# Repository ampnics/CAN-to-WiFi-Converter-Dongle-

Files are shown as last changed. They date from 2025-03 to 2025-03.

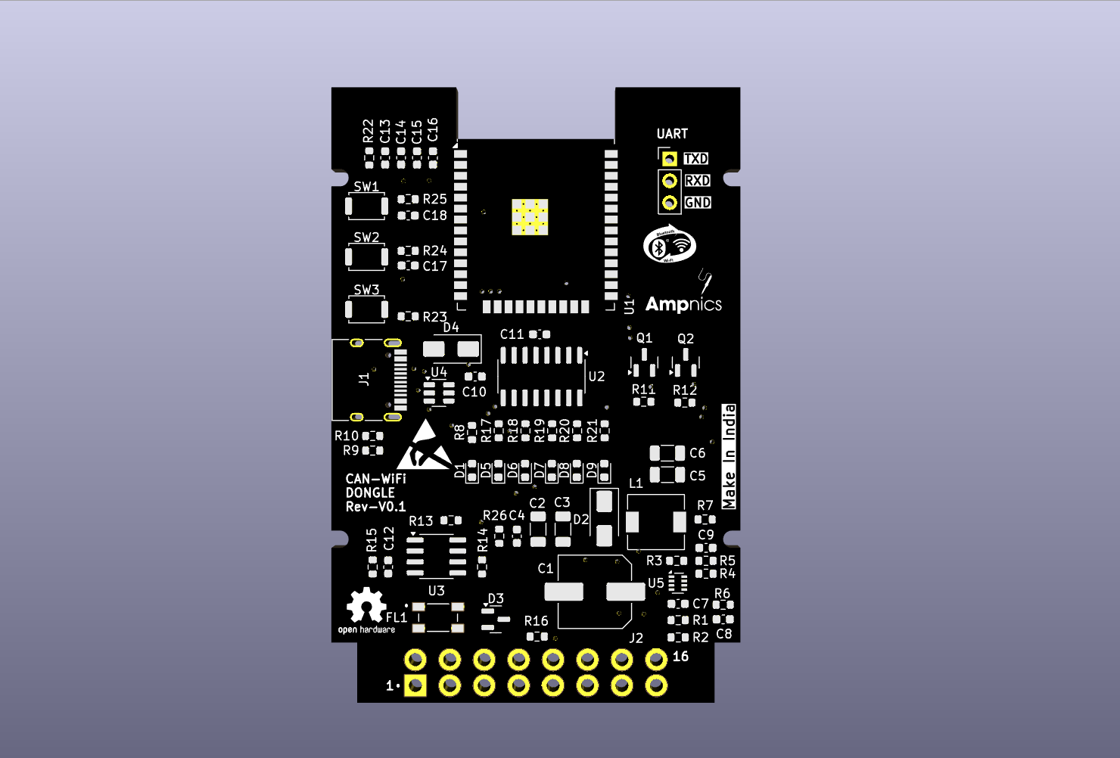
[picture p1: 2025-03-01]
ESP32_Wifi2CAN_Rev0.1/Docs/PCB.png

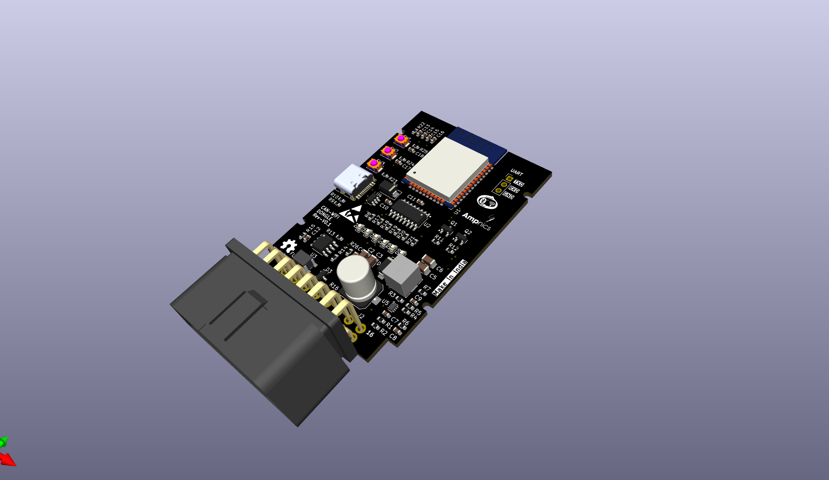
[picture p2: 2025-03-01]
ESP32_Wifi2CAN_Rev0.1/Docs/img.png

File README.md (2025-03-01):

Overview
This repository contains the PCB design files for a CAN to WiFi converter based on the ESP32. The design allows seamless communication between a Controller Area Network (CAN) bus and WiFi, making it ideal for automotive and IoT applications.

Features

ESP32-based CAN to WiFi bridge

Supports CAN 2.0 communication

Onboard 12V to 5V buck converter for efficient power management

Designed using KiCad
Compact and optimized PCB layout for reliable signal integrity

Project Structure
/schematics/ – KiCad schematic files
/pcb/ – PCB layout files
/gerber/ – Fabrication-ready Gerber files
/bom/ – Bill of Materials (BOM)
/firmware/ – (Optional) ESP32 firmware for CAN-WiFi bridging
Getting Started

Clone the repository:
bash
Copy
Edit
git clone https://github.com/ampnics/CAN-to-WiFi-Converter-Dongle-/
Open the KiCad project files in KiCad v6 or later.
Modify or generate Gerber files for PCB fabrication.
(Optional) Flash the ESP32 firmware for testing.

Requirements

KiCad 6+ for schematic and PCB design
ESP32 Development Environment (if using firmware)
CAN Transceiver Module (e.g., SN65HVD230)

License

This project is licensed under the MIT License – feel free to modify and distribute!

Contributing
Pull requests and improvements are welcome! If you find any issues, feel free to open an issue in the repository.

Author
Developed by Md Ammar Maniyar (@ampnics). Reach out for collaboration or feedback!

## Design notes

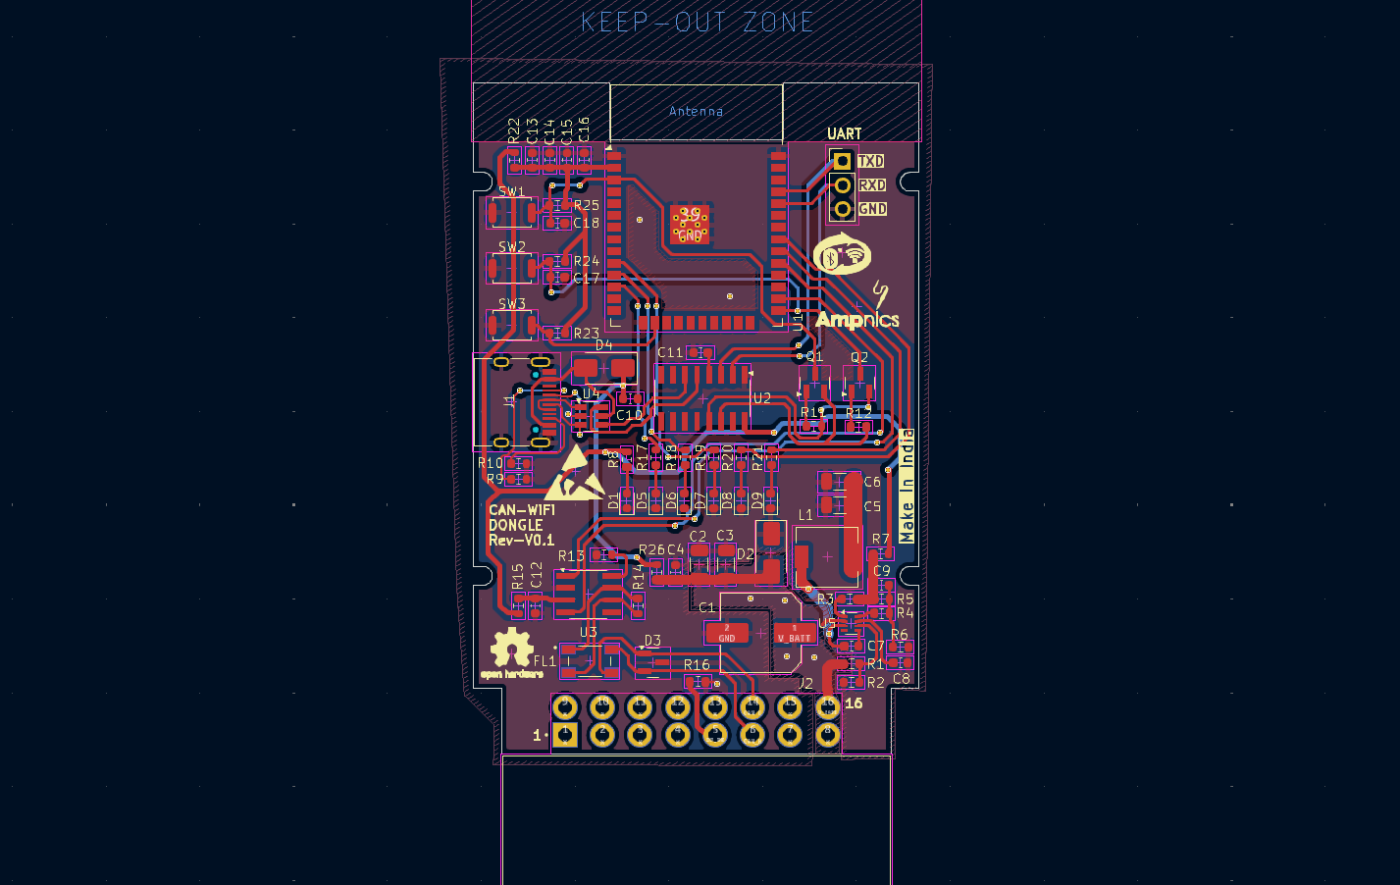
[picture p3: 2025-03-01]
ESP32_Wifi2CAN_Rev0.1/Docs/Layout.png

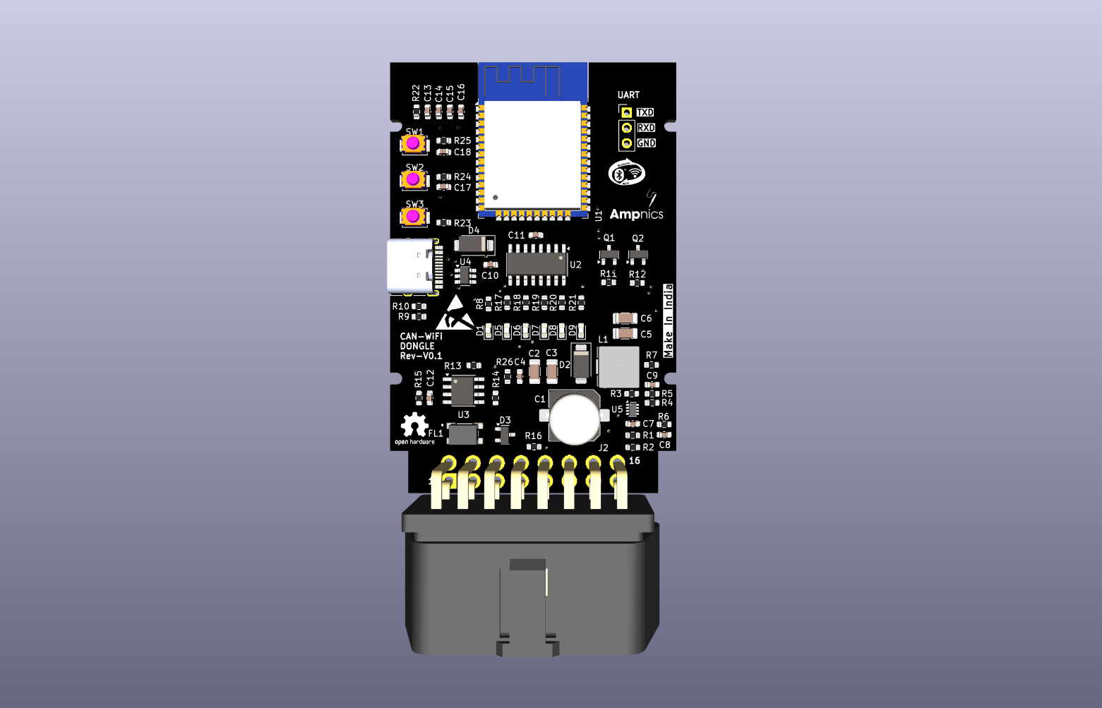
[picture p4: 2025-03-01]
ESP32_Wifi2CAN_Rev0.1/Docs/Top_View.png

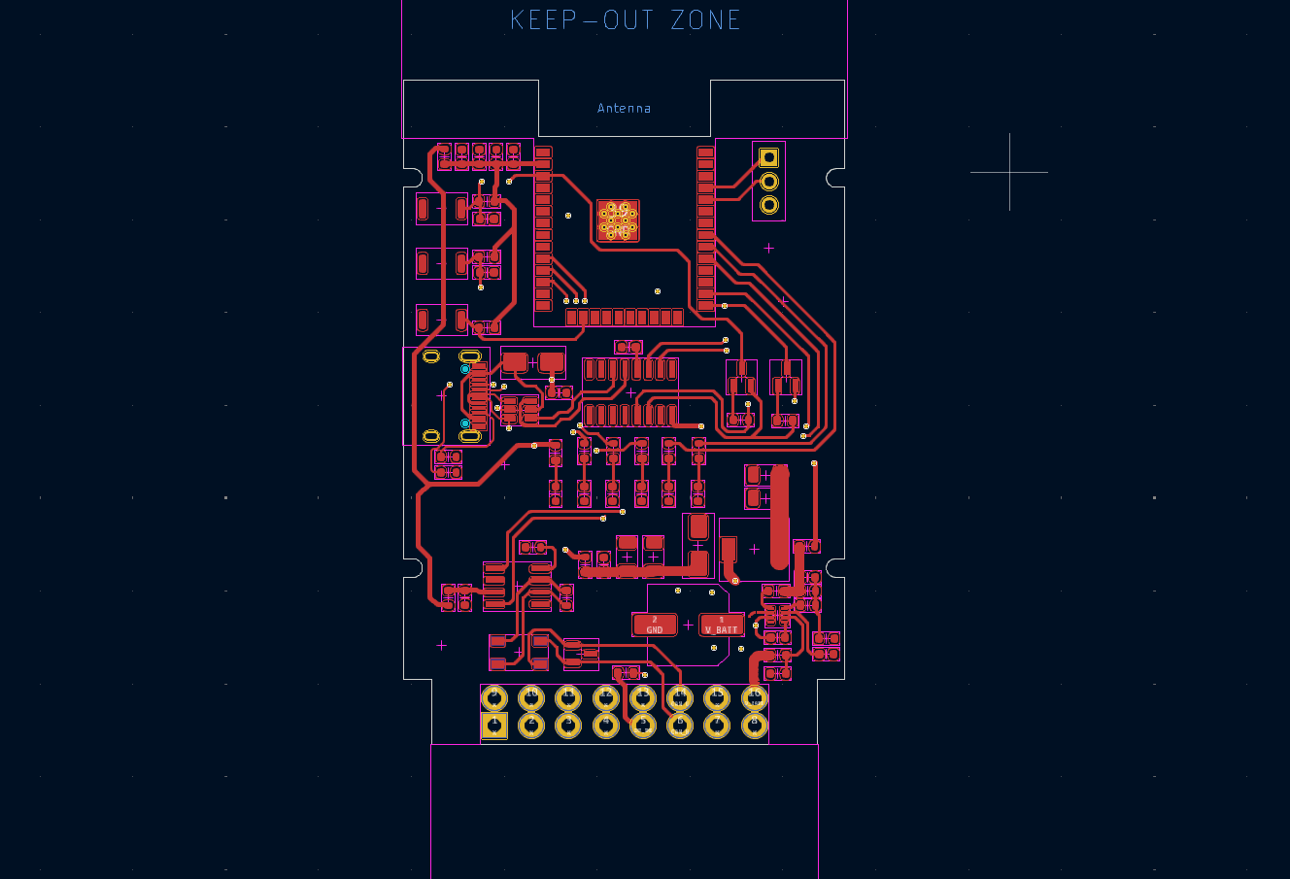
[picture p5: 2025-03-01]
ESP32_Wifi2CAN_Rev0.1/Docs/Top_Layout.png

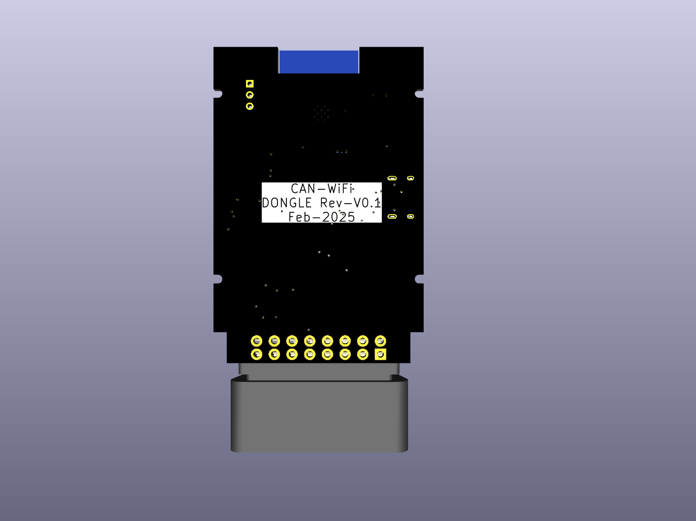
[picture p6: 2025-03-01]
ESP32_Wifi2CAN_Rev0.1/Docs/Bottom_View.png

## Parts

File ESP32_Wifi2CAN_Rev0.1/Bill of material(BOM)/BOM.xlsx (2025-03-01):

CAN to WiFI Converter
Reference | Value | Footprint | Qty
C1 | 220uF | Capacitor_SMD:C_Elec_8x10.2 | 1
C2,C3,C10 | 10uF | -- mixed values -- | 3
C4,C7,C12,C13,C14,C15,C16,C17,C18 | 0.1uF | Capacitor_SMD:C_0603_1608Metric | 9
C5,C6 | 22uF | Capacitor_SMD:C_1206_3216Metric | 2
C8 | 22nF | Capacitor_SMD:C_0603_1608Metric | 1
C9 | 470pF | Capacitor_SMD:C_0603_1608Metric | 1
C11 | 10nF | Capacitor_SMD:C_0603_1608Metric | 1
D1,D5,D6,D7,D8,D9 | LED | LED_SMD:LED_0603_1608Metric | 6
D2 | SMAJ15CA | Diode_SMD:D_SMA | 1
D3 | SZNUP2105L | Package_TO_SOT_SMD:SOT-23 | 1
D4 | SS14 | Diode_SMD:D_SMA | 1
FL1 | ACT45B-510-2P-TL003 | ACT45B-510-2P-TL003:FIL_ACT45B-510-2P-TL003 | 1
J1 | USB_C_Receptacle_USB2.0_16P | Connector_USB:USB_C_Receptacle_HRO_TYPE-C-31-M-12 | 1
J2 | C-OBD-II-16M | C-OBD-II-16M:COMTECH_C-OBD-II-16M | 1
J3 | Conn_01x03_Pin | Connector_PinHeader_2.54mm:PinHeader_1x03_P2.54mm_Vertical | 1
L1 | 6.8uH | Inductor_SMD:L_6.3x6.3_H3 | 1
Q1,Q2 | SS8050 | Package_TO_SOT_SMD:SOT-23 | 2
R1 | 191K | Resistor_SMD:R_0603_1608Metric | 1
R2 | 49.9K | Resistor_SMD:R_0603_1608Metric | 1
R3 | 100K | Resistor_SMD:R_0603_1608Metric | 1
R4,R11,R12,R23,R24,R25 | 10K | Resistor_SMD:R_0603_1608Metric | 6
R5 | 51K | Resistor_SMD:R_0603_1608Metric | 1
R6 | 9.09K | Resistor_SMD:R_0603_1608Metric | 1
R7,R15,R16,R22,R26 | 0E | Resistor_SMD:R_0603_1608Metric | 5
R8,R17,R18,R19,R20,R21 | 1K | Resistor_SMD:R_0603_1608Metric | 6
R9,R10 | 5.1K | Resistor_SMD:R_0603_1608Metric | 2
R13 | 2.4K | Resistor_SMD:R_0603_1608Metric | 1
R14 | 120E | Resistor_SMD:R_0603_1608Metric | 1
SW1,SW2,SW3 | SW_Push | Button_Switch_SMD:SW_Push_SPST_NO_Alps_SKRK | 3
U1 | ESP32-WROOM-32 | RF_Module:ESP32-WROOM-32 | 1
U2 | CH340C | Package_SO:SOIC-16_3.9x9.9mm_P1.27mm | 1
U3 | SN65HVD230 | Package_SO:SOIC-8_3.9x4.9mm_P1.27mm | 1
U4 | USBLC6-4SC6 | Package_TO_SOT_SMD:SOT-23-6 | 1
U5 | MP2338GTL-P | Package_TO_SOT_SMD:SOT-583-8 | 1

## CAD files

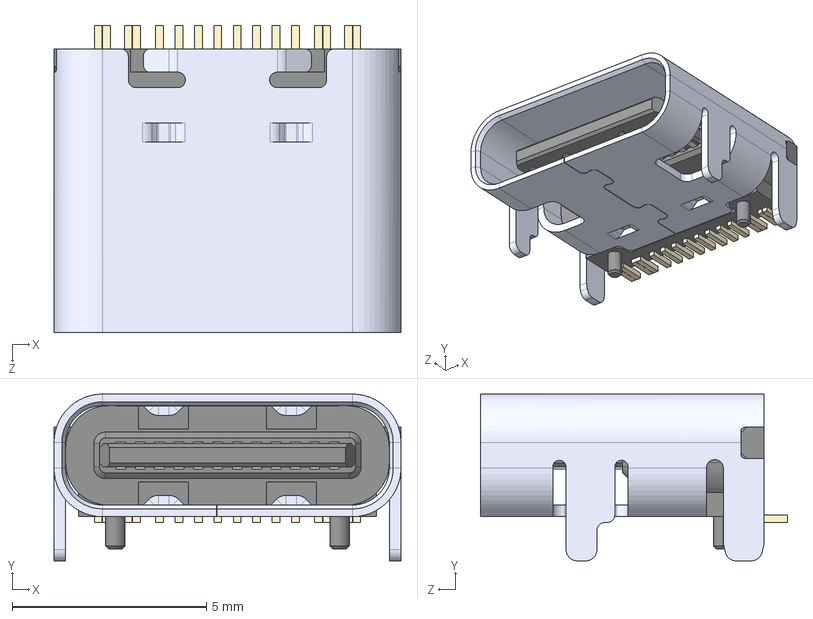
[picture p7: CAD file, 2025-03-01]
ESP32_Wifi2CAN_Rev0.1/External 3D models/TYPE-C-31-M-12--3DModel-STEP-56544.STEP
8.94 x 4.30 x 7.90 mm

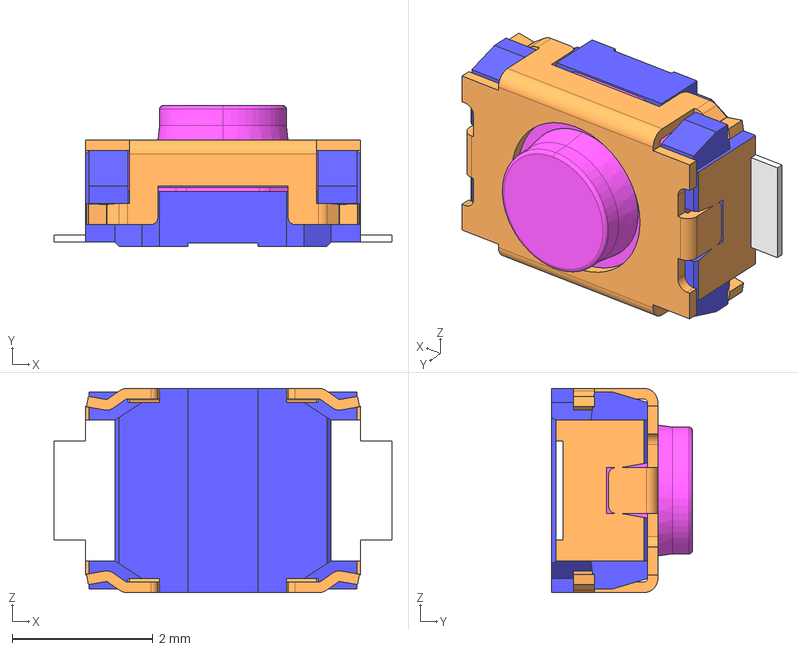
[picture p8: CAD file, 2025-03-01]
ESP32_Wifi2CAN_Rev0.1/External Libraries/158774447-659-skrkaee010/skrkaee010.stp
4.80 x 2.00 x 2.90 mm

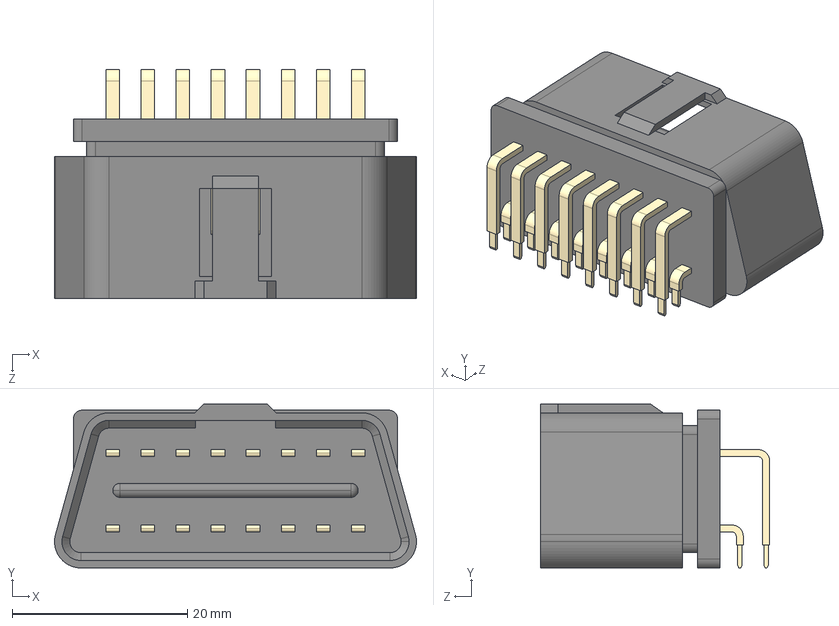
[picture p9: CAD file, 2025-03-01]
ESP32_Wifi2CAN_Rev0.1/External Libraries/C-OBD-II-16M/C-OBD-II-16M.step
41.3 x 18.7 x 26.2 mm

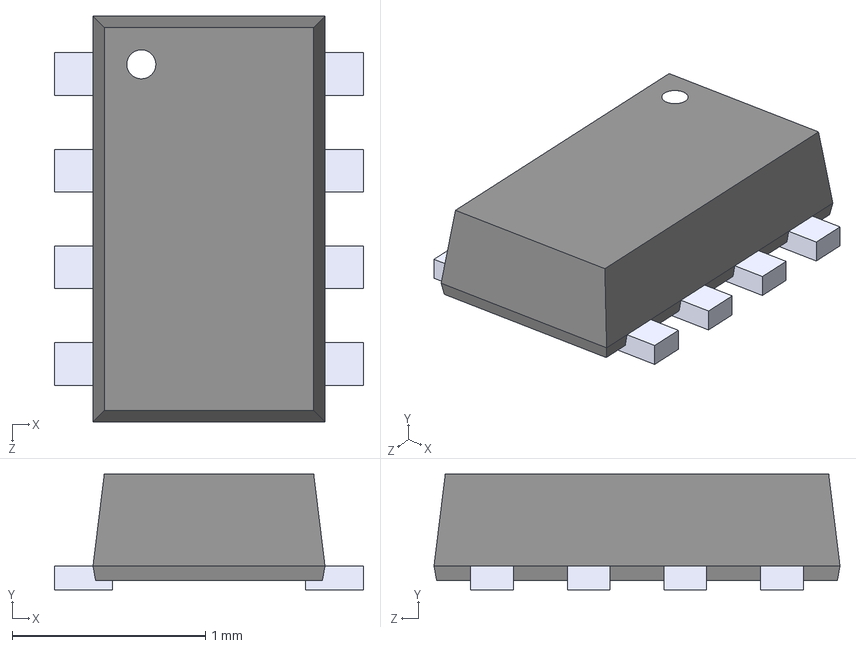
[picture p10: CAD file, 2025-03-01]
ESP32_Wifi2CAN_Rev0.1/External Libraries/MP2338GTL-P/MP2338GTL-Z--3DModel-STEP-510211.STEP
1.60 x 0.6 x 2.10 mm

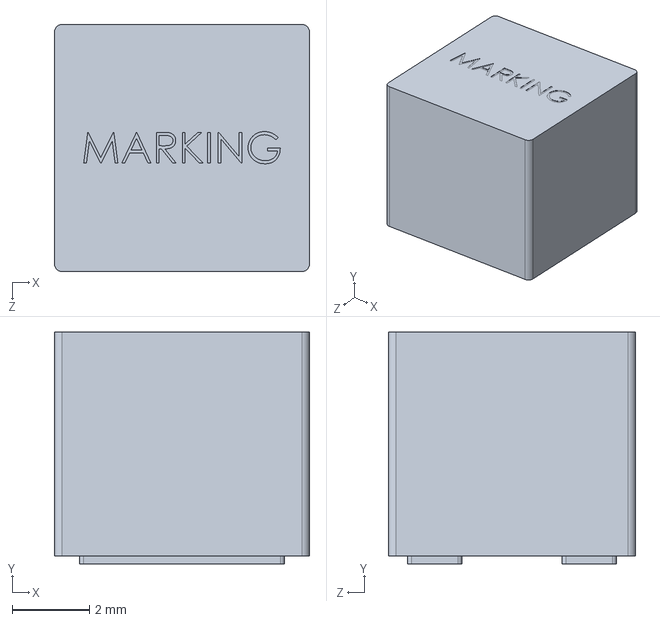
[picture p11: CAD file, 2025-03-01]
ESP32_Wifi2CAN_Rev0.1/External 3D models/MPL-AL6060-xxx.STEP
6.60 x 6.00 x 6.40 mm

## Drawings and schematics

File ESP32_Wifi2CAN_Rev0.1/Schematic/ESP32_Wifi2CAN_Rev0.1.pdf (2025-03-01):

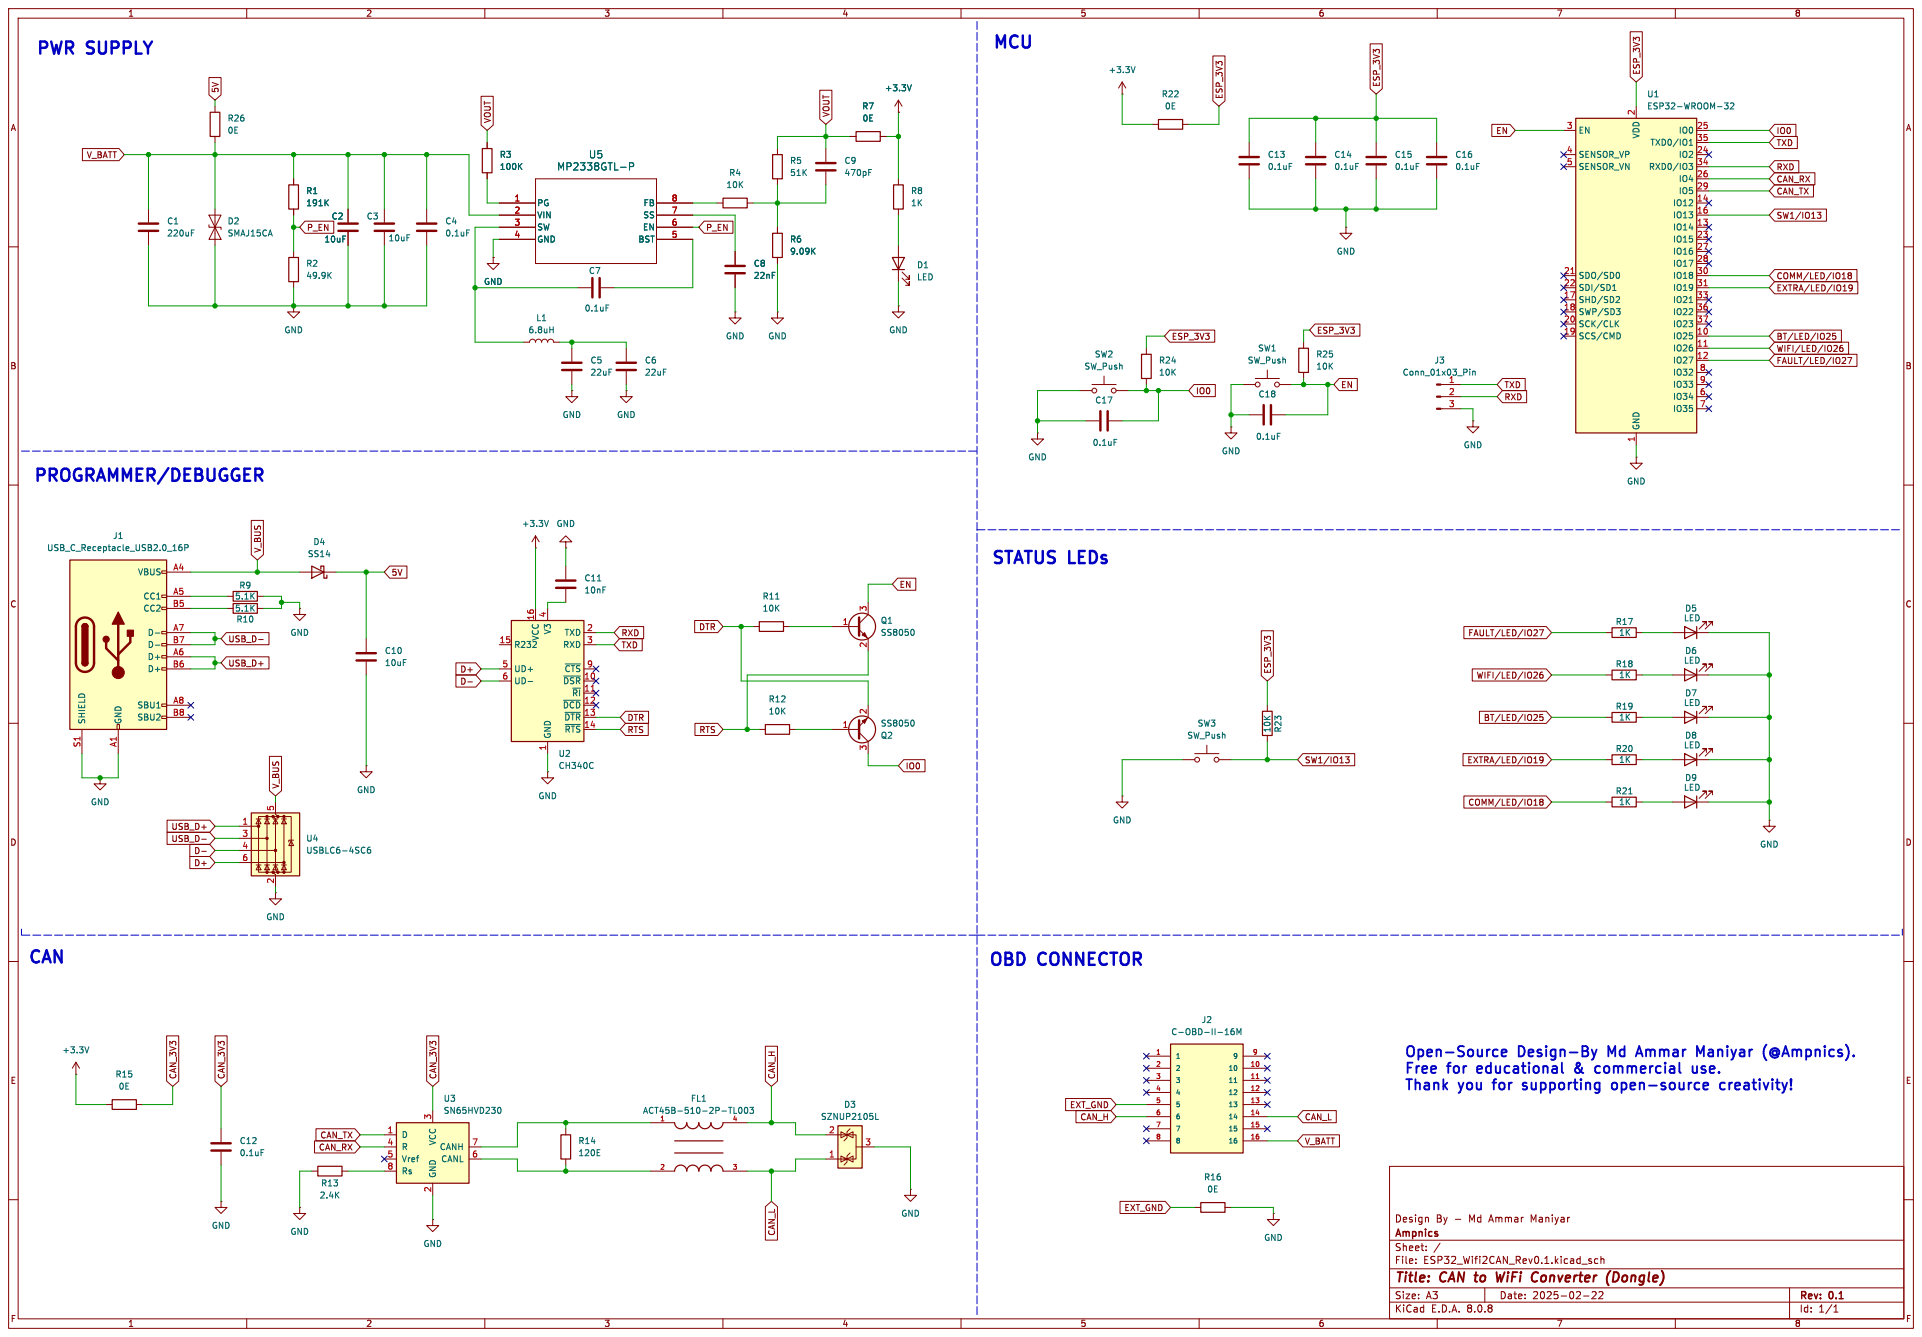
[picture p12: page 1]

1 ~{DSR} 10 ~{RI} 11 ~{DCD} 12 ~{DTR} 13 ~{RTS} 14 R232 15 VCC 16 TXD 2 RXD 3 V3

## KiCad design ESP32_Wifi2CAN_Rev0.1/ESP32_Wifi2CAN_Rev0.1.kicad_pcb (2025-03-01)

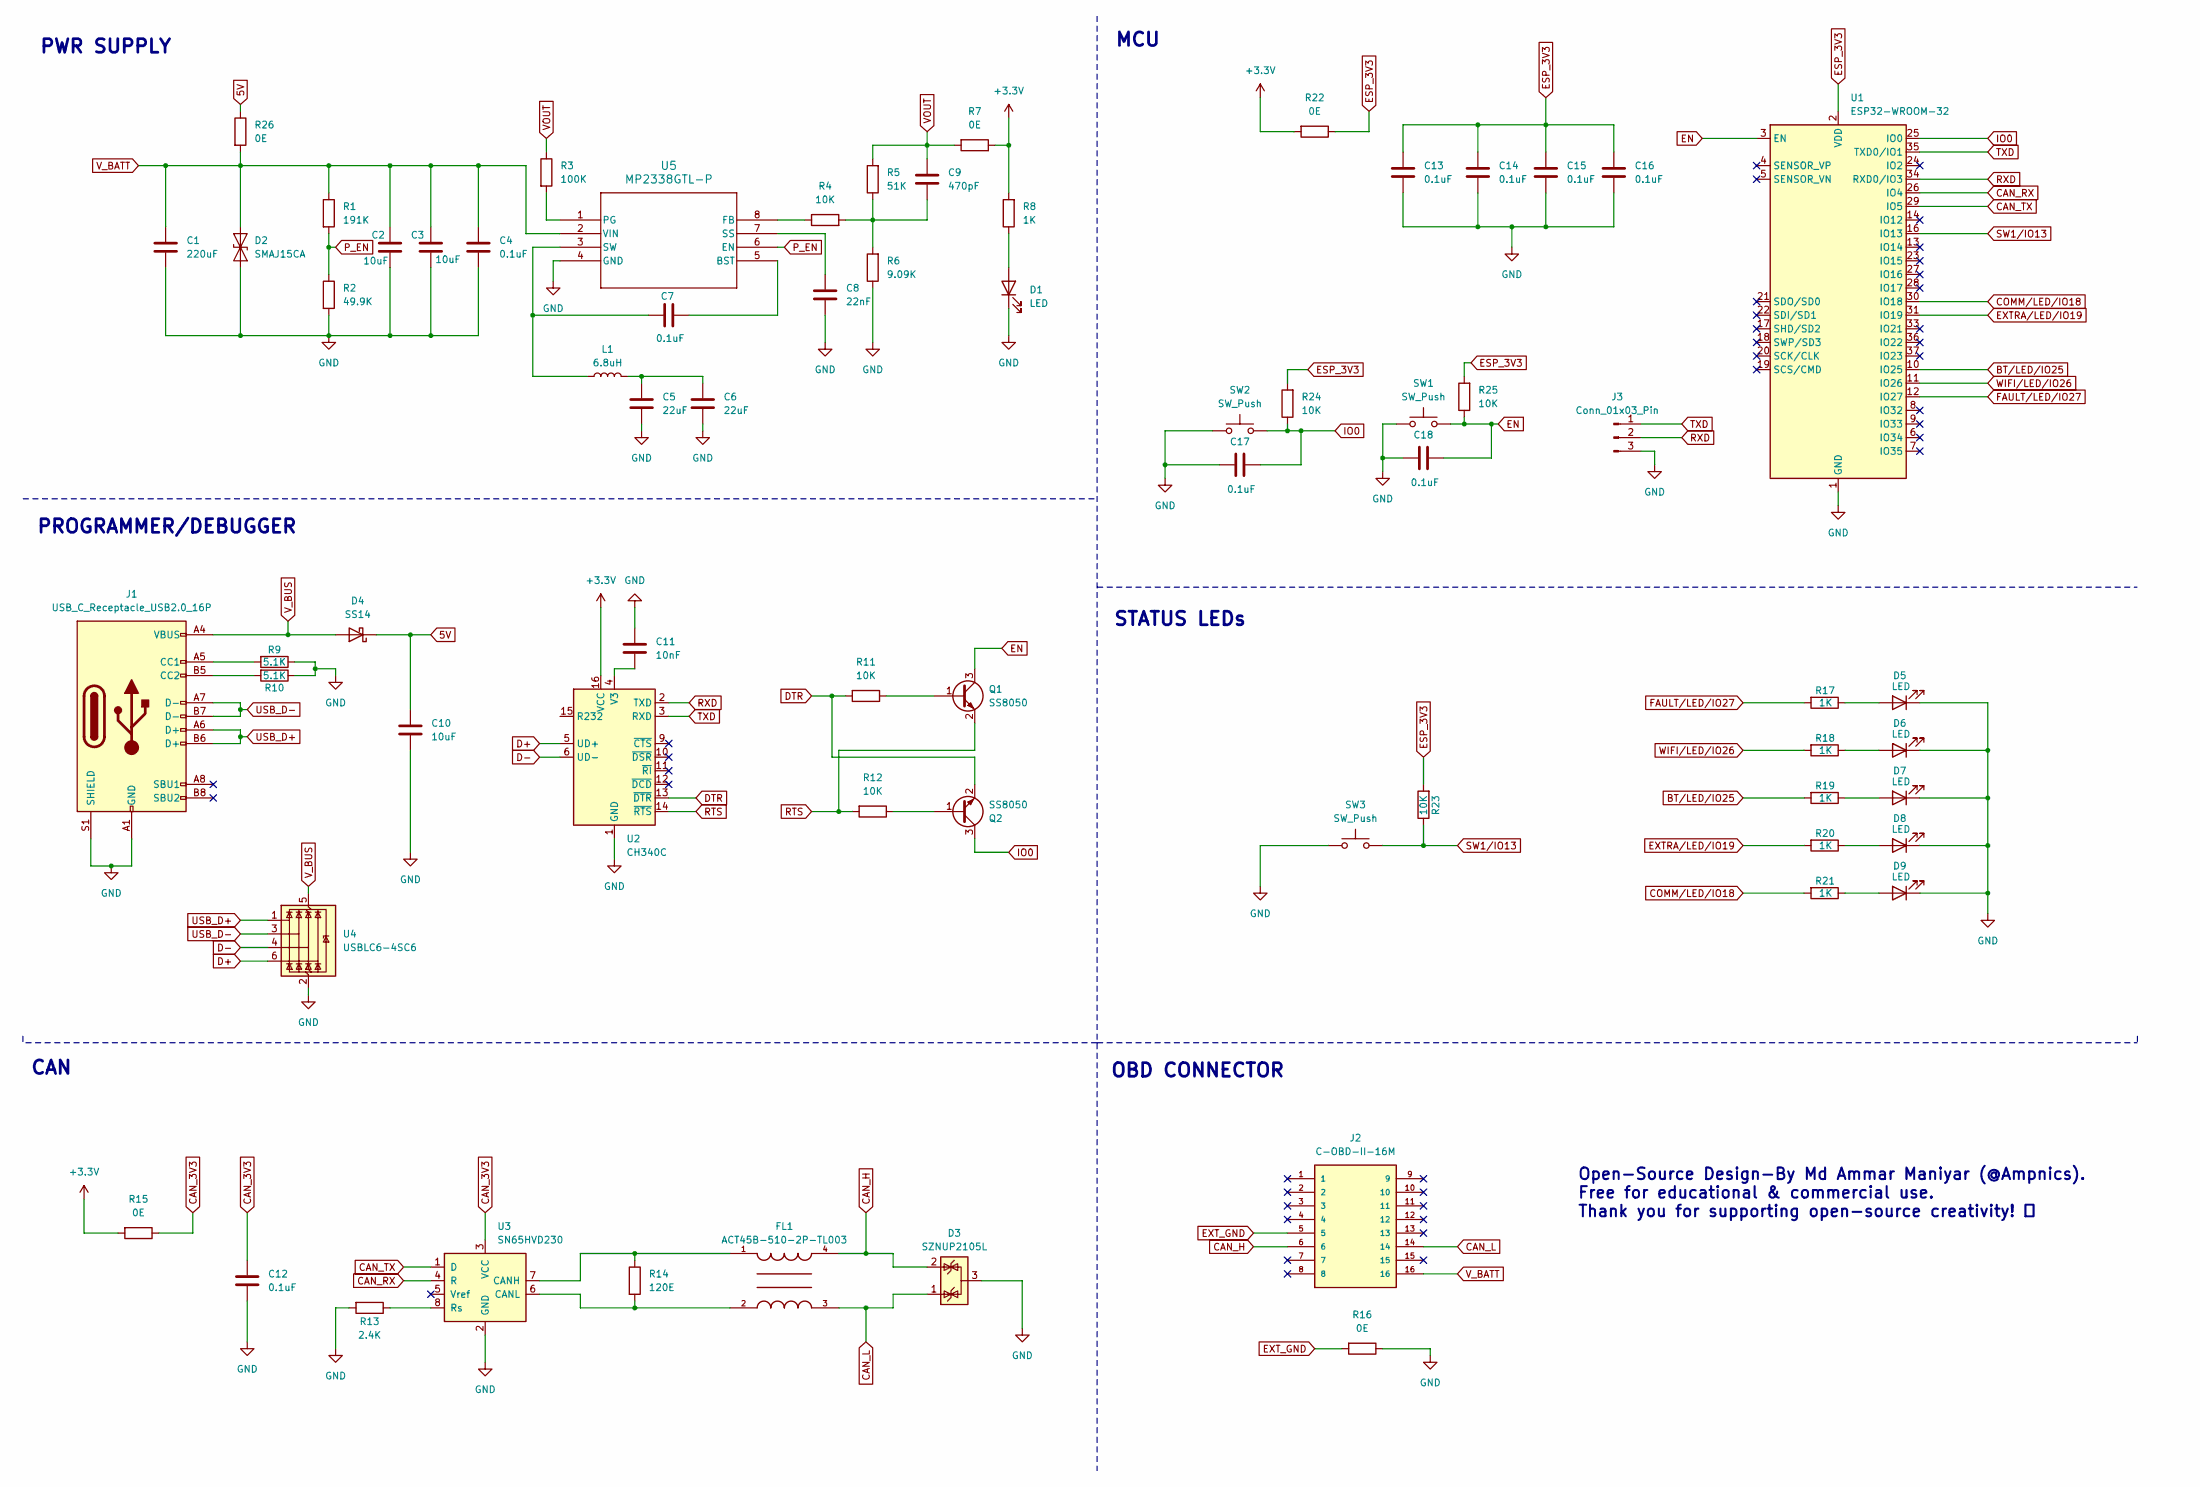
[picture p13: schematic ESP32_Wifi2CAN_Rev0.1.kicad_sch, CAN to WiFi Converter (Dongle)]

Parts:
C1: 220uF; C_Elec_8x10.2
C2, C3: 10uF; C_1206_3216Metric
C4, C7, C12, C13, C14, C15, C16, C17, C18: 0.1uF; C_0603_1608Metric
C5, C6: 22uF; C_1206_3216Metric
C8: 22nF; C_0603_1608Metric
C9: 470pF; C_0603_1608Metric
C10: 10uF; C_0603_1608Metric
C11: 10nF; C_0603_1608Metric
D1, D5, D6, D7, D8, D9: LED; LED_0603_1608Metric
D2: SMAJ15CA; D_SMA
D3: SZNUP2105L; SOT-23
D4: SS14; D_SMA
FL1: ACT45B-510-2P-TL003; FIL_ACT45B-510-2P-TL003; PARTREV 20200405
J1: USB_C_Receptacle_USB2.0_16P; USB_C_Receptacle_HRO_TYPE-C-31-M-12
J2: C-OBD-II-16M; COMTECH_C-OBD-II-16M; PARTREV A
J3: Conn_01x03_Pin; PinHeader_1x03_P2.54mm_Vertical
L1: 6.8uH; L_6.3x6.3_H3
Q1, Q2: SS8050; SOT-23
R1: 191K; R_0603_1608Metric
R2: 49.9K; R_0603_1608Metric
R3: 100K; R_0603_1608Metric
R4, R11, R12, R23, R24, R25: 10K; R_0603_1608Metric
R5: 51K; R_0603_1608Metric
R6: 9.09K; R_0603_1608Metric
R7, R15, R16, R22, R26: 0E; R_0603_1608Metric
R8, R17, R18, R19, R20, R21: 1K; R_0603_1608Metric
R9, R10: 5.1K; R_0603_1608Metric
R13: 2.4K; R_0603_1608Metric
R14: 120E; R_0603_1608Metric
SW1, SW2, SW3: SW_Push; SW_Push_SPST_NO_Alps_SKRK
U1: ESP32-WROOM-32
U2: CH340C; SOIC-16_3.9x9.9mm_P1.27mm
U3: SN65HVD230; SOIC-8_3.9x4.9mm_P1.27mm
U4: USBLC6-4SC6; SOT-23-6
U5: MP2338GTL-P; SOT-583-8

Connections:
5V: C10.1, D4.1 (K), R26.1
+3.3V: R7.1, R8.2, R15.2, R22.2, U2.16 (VCC)
BT/LED/IO25: R19.2, U1.10 (IO25)
CAN_3V3: C12.1, R15.1, U3.3 (VCC)
CAN_H: D3.2 (K), FL1.4, J2.6
CAN_L: D3.1 (K), FL1.3, J2.14
CAN_RX: U1.26 (IO4), U3.4 (R)
CAN_TX: U1.29 (IO5), U3.1 (D)
COMM/LED/IO18: R21.2, U1.30 (IO18)
D+: U2.5 (UD+), U4.6 (I/O4)
D-: U2.6 (UD-), U4.4 (I/O3)
DTR: Q2.2 (E), R11.2, U2.13 (~DTR)
EN: C18.2, Q1.3 (C), R25.1, SW1.2, U1.3 (EN)
ESP_3V3: C13.1, C14.1, C15.1, C16.1, R22.1, R23.2, R24.2, R25.2, U1.2 (VDD)
EXTRA/LED/IO19: R20.2, U1.31 (IO19)
EXT_GND: J2.5, R16.2
FAULT/LED/IO27: R17.2, U1.12 (IO27)
GND: C1.2, C2.2, C3.2, C4.2, C5.2, C6.2, C8.2, C10.2, C11.1, C12.2, C13.2, C14.2, C15.2, C16.2, C17.1, C18.1, D1.1 (K), D2.1 (A1), D3.3 (A), D5.1 (K), D6.1 (K), D7.1 (K), D8.1 (K), D9.1 (K), J1.A1 (GND), J1.A12 (GND), J1.B1 (GND), J1.B12 (GND), J1.S1 (SHIELD), J3.3, R2.2, R6.1, R9.1, R10.1, R13.2, R16.1, SW1.1, SW2.1, SW3.1, U1.1 (GND), U1.15 (GND), U1.38 (GND), U1.39 (GND), U2.1 (GND), U3.2 (GND), U4.2 (GND), U5.4 (GND)
IO0: C17.2, Q2.3 (C), R24.1, SW2.2, U1.25 (IO0)
unnamed: C5.1, C6.1, L1.2
unnamed: C9.2, R4.2, R5.1, R6.2
unnamed: D1.2 (A), R8.1
unnamed: D5.2 (A), R17.1
unnamed: D6.2 (A), R18.1
unnamed: D7.2 (A), R19.1
unnamed: D8.2 (A), R20.1
unnamed: D9.2 (A), R21.1
unnamed: J1.A5 (CC1), R9.2
unnamed: J1.B5 (CC2), R10.2
unnamed: Q1.1 (B), R11.1
unnamed: Q2.1 (B), R12.1
unnamed: C11.2, U2.4 (V3)
unnamed: FL1.1, R14.1, U3.7 (CANH)
unnamed: FL1.2, R14.2, U3.6 (CANL)
unnamed: R13.1, U3.8 (Rs)
unnamed: C7.2, U5.5 (BST)
unnamed: R4.1, U5.8 (FB)
unnamed: R3.2, U5.1 (PG)
unnamed: C8.1, U5.7 (SS)
unnamed: C7.1, L1.1, U5.3 (SW)
P_EN: R1.2, R2.1, U5.6 (EN)
RTS: Q1.2 (E), R12.2, U2.14 (~RTS)
RXD: J3.2, U1.34 (RXD0/IO3), U2.2 (TXD)
SW1/IO13: R23.1, SW3.2, U1.16 (IO13)
TXD: J3.1, U1.35 (TXD0/IO1), U2.3 (RXD)
USB_D+: J1.A6 (D+), J1.B6 (D+), U4.1 (I/O1)
USB_D-: J1.A7 (D-), J1.B7 (D-), U4.3 (I/O2)
VOUT: C9.1, R3.1, R5.2, R7.2
V_BATT: C1.1, C2.1, C3.1, C4.1, D2.2 (A2), J2.16, R1.1, R26.2, U5.2 (VIN)
V_BUS: D4.2 (A), J1.A4 (VBUS), J1.A9 (VBUS), J1.B4 (VBUS), J1.B9 (VBUS), U4.5 (VBUS)
WIFI/LED/IO26: R18.2, U1.11 (IO26)

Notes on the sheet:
MCU
STATUS LEDs
OBD CONNECTOR
CAN
Open-Source Design-By Md Ammar Maniyar (@Ampnics). Free for educational & commercial use. Thank you for supporting open-source creativity! 🌟
PWR SUPPLY
PROGRAMMER/DEBUGGER

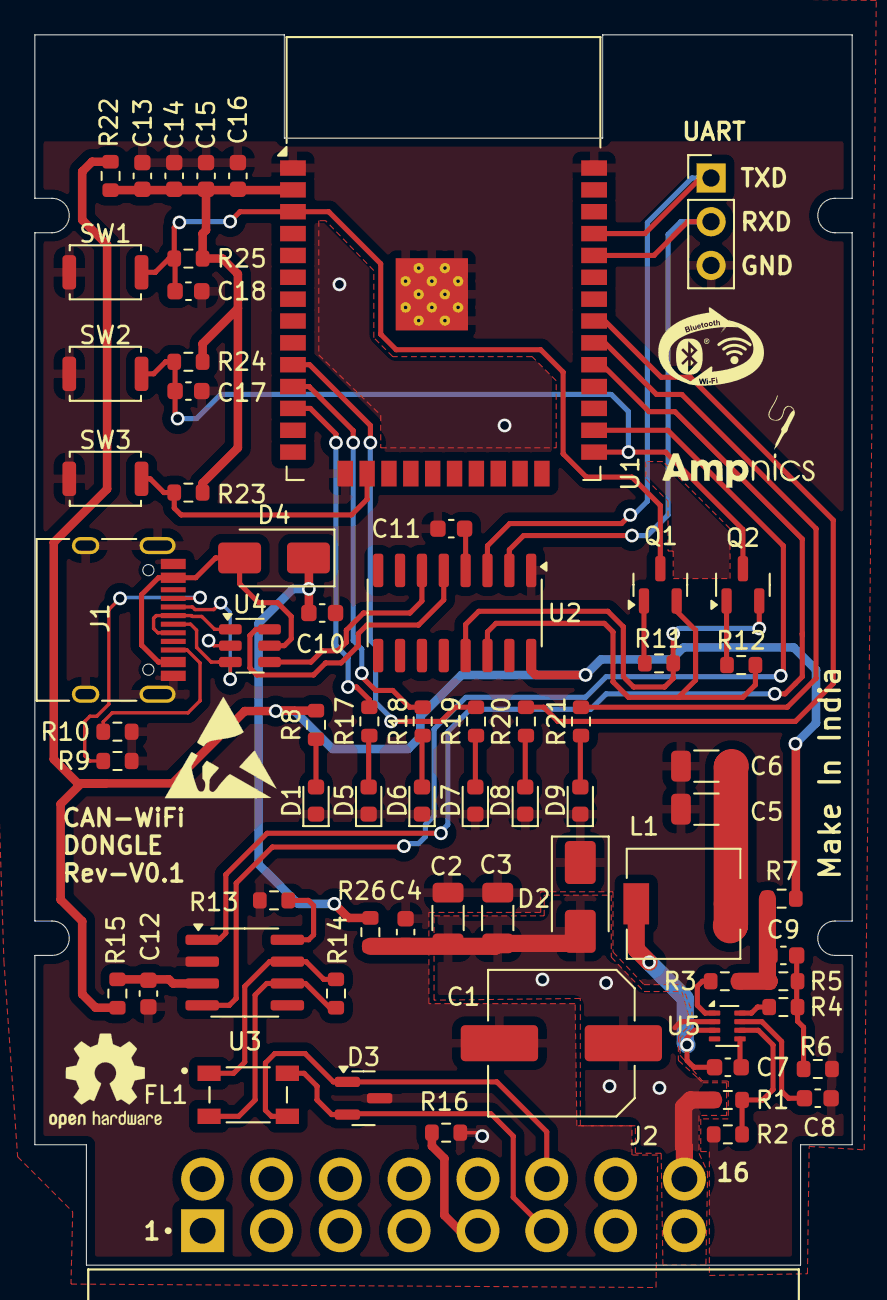
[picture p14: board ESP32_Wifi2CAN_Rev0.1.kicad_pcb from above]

Board: 2 copper layers, 47.5 x 71.5 mm, 68 parts (0 on the bottom side), 51 nets.
